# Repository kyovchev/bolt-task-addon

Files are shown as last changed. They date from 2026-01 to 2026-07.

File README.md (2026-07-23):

# Bolt Task Addon for Task Board TBv2023

This repository contains the Bolt Task Addon for Task Board version 2023 found in [https://github.com/peterso/robotlearningblock](https://github.com/peterso/robotlearningblock).

The Bolt Task requires the robot to unscrew a bolt, move it to another position and screw it again. During the operation the robot must not exceed predefined pressure force over the bolt task assembly.

**IMPORTANT NOTE: The latest version is Type B V2. It uses M8x30mm bolt and provides brackets for direct mount to the box or to a DIN rail.**

## Introduction

Two different protopyes of the task addon are developed:
- **Type A**
   
   The presence of the bolt is detected by two [M5Stack Unit 180](https://docs.m5stack.com/en/unit/OP180).
   
   Video demonstration of the first Type A prototype and the task performed by a human can be found in the following video [https://youtu.be/7AfbINjLBa4](https://youtu.be/7AfbINjLBa4):

   Bolt Task Addon Type A for TBv2023 - First Prototype Demo (https://youtu.be/7AfbINjLBa4)

- **Type B**

   The presence of the bolt is detected by simple circuit connection similar to the connection of the terminal block of TBv2023 for PbHub port 3 as decribed in the original [peterso/robotlearningblock/Assembly of Task Board 2023_V2.pdf](https://drive.google.com/file/d/1LZS_wPafdJOO1Q0lu-8TDO9xGrxpoSBB/view?usp=sharing).

   The Type B design is more compact and might be used together wih the terminal block if more digital pins are available or second hub is added. This design checks whether the bolt is fully tightened. After the bolt is slightly loose there will be no signal on the digital pins. The robot will need to do 3 full turns to release the bolt.

   Video demonstration of the first Type B prototype and the task performed by a human can be found in the following video [https://youtu.be/U2pmAaK7oM4](https://youtu.be/U2pmAaK7oM4):

   Bolt Task Addon Type B for TBv2023 - First Prototype Demo (https://youtu.be/U2pmAaK7oM4)

## Force measurement

For both designs the force is measured by one [M5Stack Unit Mini Scales (SKU:U177)](https://docs.m5stack.com/en/unit/Unit-Mini%20Scales).

Sample graphing of the force on the scales unit during operation when Type B design is used is shown in the following figure:

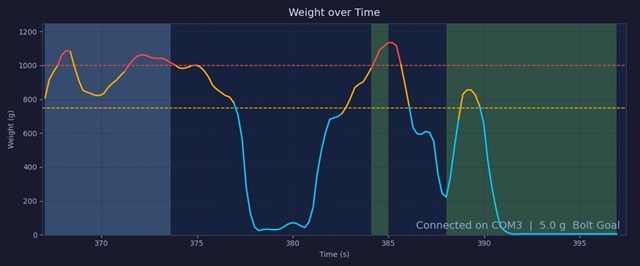
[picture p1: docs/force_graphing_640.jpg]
Force Graphing


Video demonstration of the measured force when Type B design is used is shown in the following video [https://youtu.be/ekPisNhrMn4](https://youtu.be/ekPisNhrMn4):

Bolt Task Addon Type B for TBv2023 - Force Measurement Demo (https://youtu.be/ekPisNhrMn4)

## Firmware

The used controller is [M5StickC-Plus2](https://docs.m5stack.com/en/core/M5StickC%20PLUS2). On the display visual feedback is provided. When the bolt is in the start position and at least 12 bolt revolutions are executed the top (left) part of the screen is blue. When the bolt is in the end position and at least 12 bolt revolutions are executed the bottom (right) part of the screen is green. When the pressure is near the max limit the screen will turn yellow. When the pressure is over the limit the screen will turn red. The Arduino test code of the first prototype for:
- **Type A** is in the folder [./M5StickCPlus2-Arduino/BoltTaskTestTypeA/](./M5StickCPlus2-Arduino/BoltTaskTestTypeA/).

- **Type B** is in the folder [./M5StickCPlus2-Arduino/BoltTaskTestTypeB/](./M5StickCPlus2-Arduino/BoltTaskTestTypeB/).

- **Type B with force graphing** firmware is in the folder [./M5StickCPlus2-Arduino/GraphingTestTypeB/](./M5StickCPlus2-Arduino/GraphingTestTypeB/). By pressing the M5 button you can toggle the graphing display. This firmware is also sending the data via serial communication. [./M5StickCPlus2-Arduino/GraphicsTestTypeB/live_graph.py](./M5StickCPlus2-Arduino/GraphingTestTypeB/live_graph.py) is a Python script for visualization of the data. Read the comments in the beggining of the file for information about the usage.

IDF and Arduino compatible firmwares for the fully assembled Task Board v2023 with the added Bolt Task Addon can be found in the folder [./TBv2023-Firmware/](./TBv2023-Firmware/).

## CAD

The Bolt Task Addon can be 3D Printed. The STLs of the parts are in the folder [./STLs/](./STLs/).

The repository contains the FreeCAD ([https://www.freecad.org/](https://www.freecad.org/)) design file for the diferrent designs:

- **Type A**

   The design file is [/CAD/BoltTaskAssembly_TypeA_V1.FCStd](/CAD/BoltTaskAssembly_TypeA_V1.FCStd).

   The Type A CAD assembly of the Bolt Task Addon is shown in the following image:

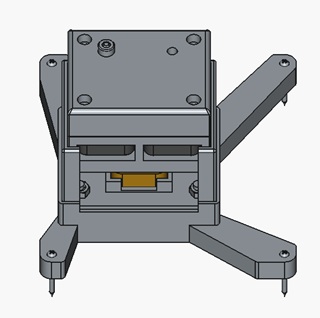
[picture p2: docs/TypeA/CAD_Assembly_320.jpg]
CAD Assembly
   

   The printed parts and the M5 Unit sensors are shown in the following image:

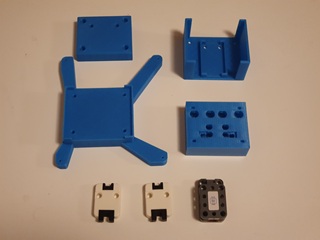
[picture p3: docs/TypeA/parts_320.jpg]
Printed Parts and M5 Unit Sensors
   

   The complete assembly mounted on the CU-3286-MB box is shown in the following image:

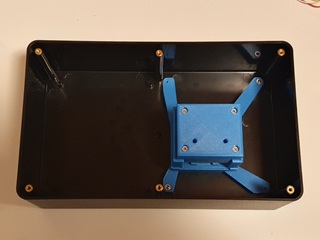
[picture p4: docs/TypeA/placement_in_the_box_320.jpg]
   

   Place two M4 nuts between the main and the top part to be used for bolt threads as shown in the image:

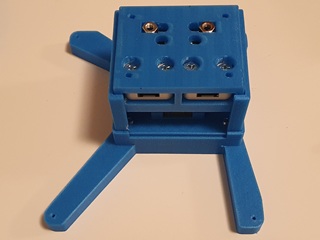
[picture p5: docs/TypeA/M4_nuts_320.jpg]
M4 nuts
   

   The Bolt Task Addon Type A with the cover of the TBv2023 is shown in the following image:
   
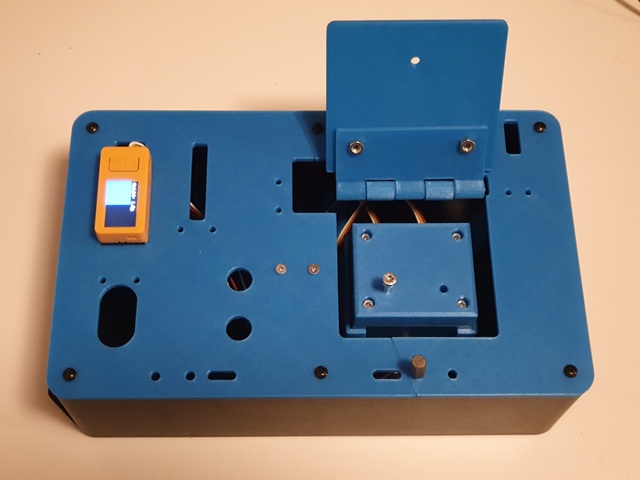
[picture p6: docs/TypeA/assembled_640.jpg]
   

- **Type B V1**

   The design file is [/CAD/BoltTaskAssembly_TypeB_V1.FCStd](/CAD/BoltTaskAssembly_TypeB_V1.FCStd).

   The Type B V1 CAD assembly of the Bolt Task Addon is shown in the following image:

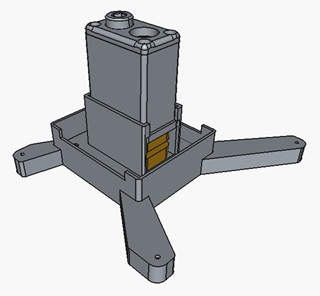
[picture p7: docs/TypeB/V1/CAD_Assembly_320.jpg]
CAD Assembly
   

   For this design we are using M8x40mm bolt. The used washers are one with InnerD=10.50mm, OuterD=19.80mm, Thickness=1.77mm and two InnerD=5.30mm, OuterD=14.85mm, Thickness=1.18mm. The printed parts, the M5 Mini Scales and the used hardware are shown in the following image:

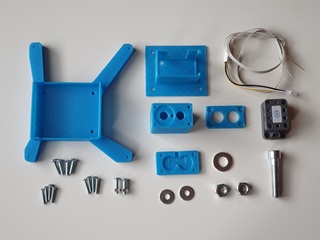
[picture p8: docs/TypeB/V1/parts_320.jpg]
Printed Parts and Hardware
   

   The washers and the M8 nuts must be placed together with the cable going to port 3 of the PbHub as shown in the following image. The black cable must be connected to the top (the bigger) washer, the white cable is to be connected to the small washer which is below the nut ot the bolt start position and the yellow cable is to be connected to the nut below the bolt goal position. The cables must be positioned carefully so that they are not pinched by the washers when the bolt is tightened. The black cable must be routed through the hole in the main block.

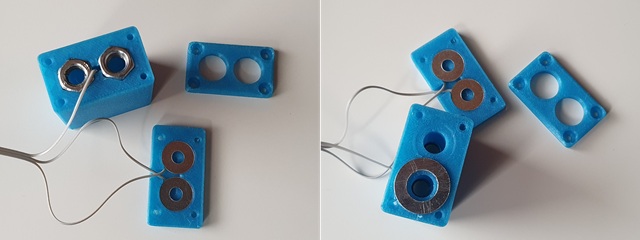
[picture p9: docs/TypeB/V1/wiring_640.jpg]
Wiring
   

   After the cables are routed then the three parts are assembled together with 8 M3 screws. Depending on the washers and the 3D print quality you might need to add one additional M3 or M4 washer between the M8 nut and the bottom washer. The M8 nut must touch the bottom washer to close the circuit with the M8 bolt. Further versions might use separate bottom caps to address this issue.

   The M5 Unit Mini Scales is attached to the base with two M4 screws. The bolt assembly is then snapped in to place on top of the base assembly. Currently, the scale is not attached with bolts to the bolt assembly. Then, the assembly is attached to the bottom bracket with 4 M4 screws and the complete assembly is mounted on the CU-3286-MB box as shown in the following image:

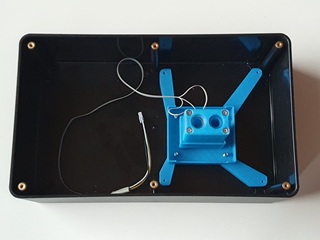
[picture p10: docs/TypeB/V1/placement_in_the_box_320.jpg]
   

   The Bolt Task Addon Type B with the cover of the TBv2023 is shown in the following image:

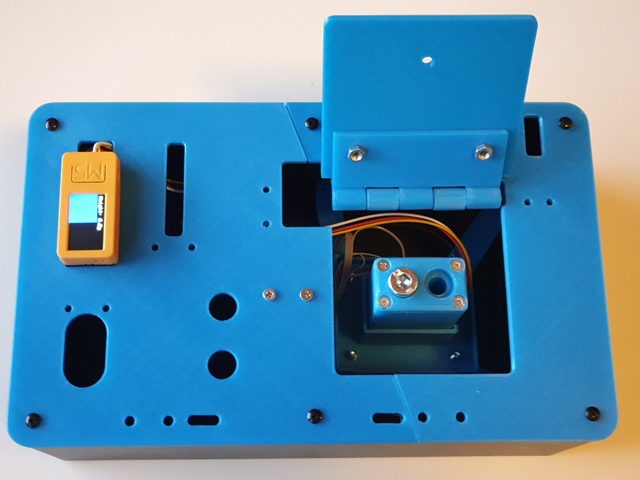
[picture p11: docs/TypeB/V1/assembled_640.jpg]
   

- **Type B V2**

   The design file is [/CAD/BoltTaskAssembly_TypeB_V2.FCStd](/CAD/BoltTaskAssembly_TypeB_V2.FCStd). There are also STEP file exports in the folder [./CAD/STEPs/](./CAD/STEPs/) which can be imported easily into other CAD softwares.

   The Type B V2 CAD assembly of the Bolt Task Addon is shown in the following image:

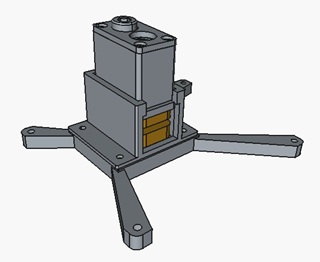
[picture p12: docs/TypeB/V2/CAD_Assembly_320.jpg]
CAD Assembly
   

   For this design we are using **M8x30mm** bolt. The used washers are one with InnerD=10.50mm, OuterD=19.80mm, Thickness=1.77mm and two InnerD=4.20mm, OuterD=11.80mm, Thickness=1.10mm.

   **Note:** You can also use a shorter **M8x25mm** bolt by using the provided [./STLs/TypeB/V2/Main_25mm.stl](./STLs/TypeB/V2/Main_25mm.stl) instead of Main.stl.

   The printed parts, the M5 Mini Scales and the used hardware are shown in the following image:

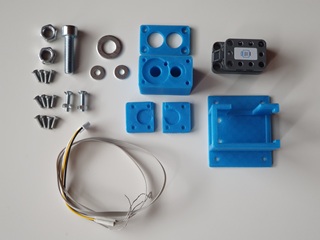
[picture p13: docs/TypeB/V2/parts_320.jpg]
Printed Parts and Hardware
   

   The washers and the M8 nuts must be placed together with the cable going to port 3 of the PbHub. The black cable must be connected to the top (the bigger) washer, the white cable is to be connected to the small washer which is below the nut ot the bolt start position and the yellow cable is to be connected to the nut below the bolt goal position. The cables must be positioned carefully so that they are not pinched by the washers when the bolt is tightened. The black cable must be routed through the hole in the main block.

   After the cables are routed then the parts are assembled together with 12 M3 screws. The M8 nuts must touch the bottom washers to close the circuit with the M8 bolt.

   The M5 Unit Mini Scales is attached to the base with two M4 screws. The bolt assembly is then snapped in to place on top of the base assembly. Currently, the scale is not attached with bolts to the bolt assembly. The assembly process is shown in the following video  [https://youtu.be/teUUwNURSHQ](https://youtu.be/teUUwNURSHQ):

   Bolt Task Addon Type B V2 for TBv2023 - Assembly Process (https://youtu.be/teUUwNURSHQ)

   After initial testing, the base part was modified to withstand a higher load. A comparison between the original and modified base is shown in the figure:

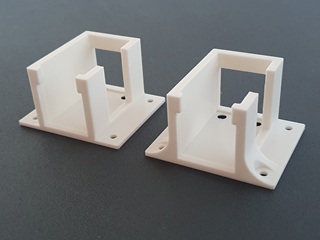
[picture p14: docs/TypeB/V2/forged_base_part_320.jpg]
Forged Base Comparison
   

   Then, the assembly is attached to the bottom bracket or DIN rail with 4 M4 screws. The complete assembly can be mounted on the CU-3286-MB box is two ways:
   - with the provided DIN rail attachments and clamping mounting blocks:

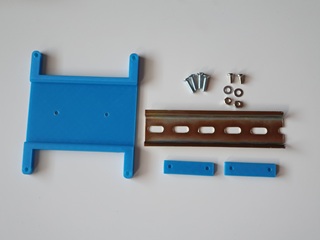
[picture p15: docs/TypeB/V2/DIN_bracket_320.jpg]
DIN bracket
      

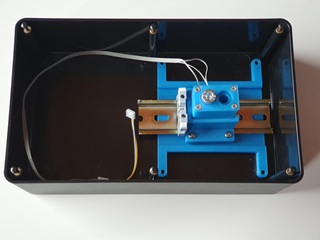
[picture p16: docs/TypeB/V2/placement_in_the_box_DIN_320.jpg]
      

   - directly to the box with the provided bracket:

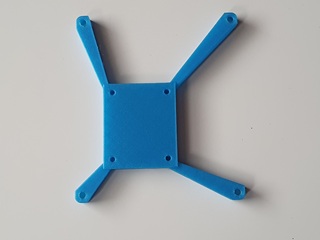
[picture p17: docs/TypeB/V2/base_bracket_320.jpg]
Base Bracket
      

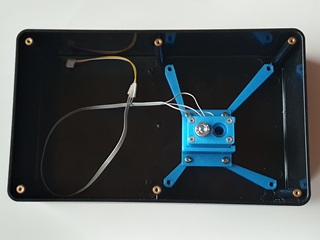
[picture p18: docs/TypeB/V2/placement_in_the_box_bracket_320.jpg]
      

   The Bolt Task Addon Type B V2 with the cover of the TBv2023 is shown in the following images:

   - with DIN rail:

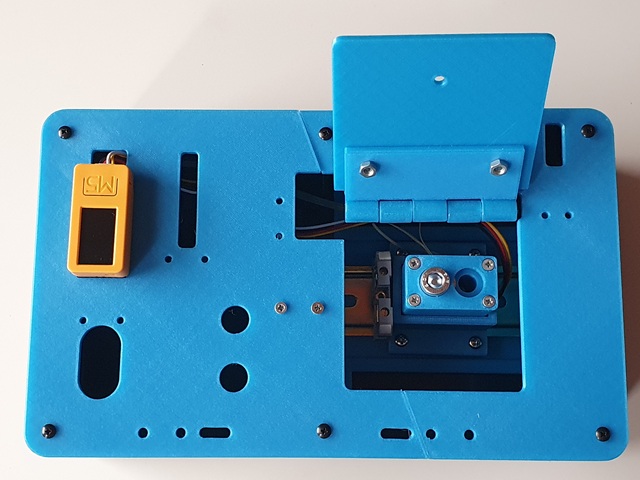
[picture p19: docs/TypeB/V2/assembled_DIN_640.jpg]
      

   - directly to the box:

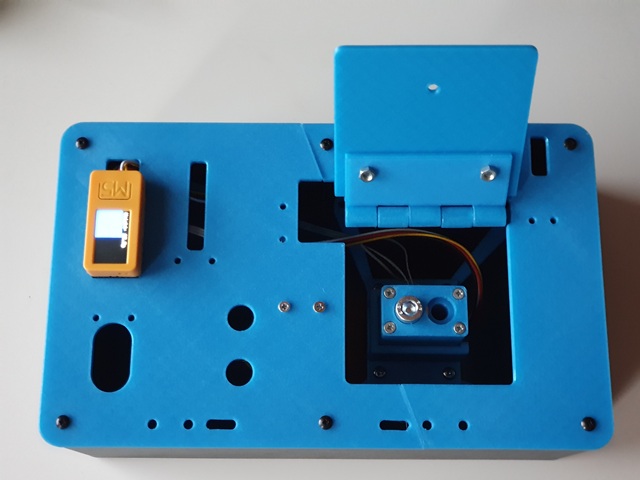
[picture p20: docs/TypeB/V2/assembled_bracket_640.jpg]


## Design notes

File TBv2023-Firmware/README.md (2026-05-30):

# Firmware for Task Board v2023 with Bolt Task Addon

This folder contains Arduino and IDF firmwares for the Task Board v2023 with the Bolt Task Addon. They are compatible with the older end-of-life M5StickC Plus2 and the current M5Stack StickS3.

The Arduino firmware is very basic and shows how to interact with all of the sensors. The Arduino firmware is in the folder [./Arduino/TBv2023_Bolt_Task_Addon/](./Arduino/TBv2023_Bolt_Task_Addon/).

The IDF firmware is an extension of the original firmware. It just made compatible with the new sensors and the newer StickS3. The original version of the firmware can be found at [https://github.com/peterso/robotlearningblock/tree/main/idf/taskboard](https://github.com/peterso/robotlearningblock/tree/main/idf/taskboard). More information about the instalation procedure can be found in the folder [./IDF/](./IDF/).

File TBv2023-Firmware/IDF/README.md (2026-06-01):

# Task Board v2023 with Bolt Task Addon IDF Firmware

The original IDF firmware can be found here: [https://github.com/peterso/robotlearningblock/tree/main/idf/taskboard](https://github.com/peterso/robotlearningblock/tree/main/idf/taskboard).

The files in the patch directory provide an easy way to extend thi original firmware and to add support for the newer M5Stack StickS3 board and for the developed Bolt Task Addon.

You can compile and flash the board with the new firmware as follows:

1. Clone this repository:
    ```bash
    git clone https://github.com/kyovchev/bolt-task-addon.git
    cd bolt-task-addon/TBv2023-Firmware/IDF
    ```

2. Clone the original IDF firmware and patch it with the updated code:
    ```bash
    git clone https://github.com/kyovchev/robotlearningblock
    cd robotlearningblock
    git submodule update --init --recursive
    cd idf/taskboard/
    rm -rf components/m5stack__m5unified/
    rm sdkconfig sdkconfig.old dependencies.lock
    sudo rm -rf build
    sudo rm -rf managed_components
    cp -rf ../../../patch/* .
    ```

3. Run the `espressif/idf:release-v5.3` docker:
    ```bash
    docker run -it --rm   -v $PWD:/workspace   -v /dev:/dev   --privileged   espressif/idf:release-v5.3
    ```

4. Inside of the docker install the required build packages:
    ```bash
    pip3 install catkin_pkg lark-parser colcon-common-extensions empy==3.3.4
    cd workspace
    ```

5. Select the target board.

    4.1. For the M5StickC-Plus2 use:
    ```bash
    idf.py set-target esp32
    ```

    4.2. For the M5 StickS3 use:
    ```bash
    idf.py set-target esp32s3
    ```

6. Select the correct task board hardware configuration in the menu:
    ```bash
    idf.py menuconfig
    ```
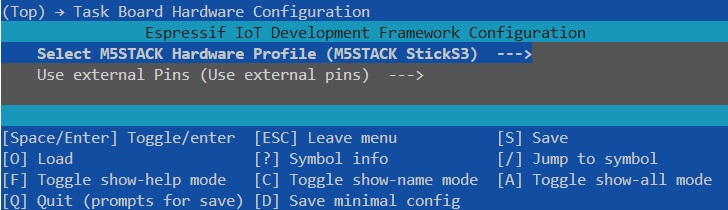
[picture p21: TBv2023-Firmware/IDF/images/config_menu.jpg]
Hardware Configuration Menu
    

7. Next you need to build the firmware:

    6.1. For the M5StickC-Plus2 use:
    ```bash
    idf.py build
    ```

    6.2. For the M5 StickS3 you might need to remove duplicated atomic_64bits before executing the build command:
    ```bash
    idf.py build
    /opt/esp/tools/xtensa-esp-elf/esp-13.2.0_20250707/xtensa-esp-elf/bin/xtensa-esp32s3-elf-ar -d /workspace/components/micro_ros_espidf_component/libmicroros.a librcutils-atomic_64bits.c.obj
    idf.py build
    ```

8. Flash the firmware:
    ```bash
    idf.py flash
    ```

9. You can use the debug monitor with:
    ```bash
    idf.py monitor
    ```

---

The order of the sensors in the PbHub and/or external pins are as follows:

- without the special Y cable:

    0 - Dual button

    1 - Left photo int sensor

    2 - Right photo int sensor

    3 - Terminal blocks

    4 - Angle sensor

    5 - Potentiometer fader

    Bottom left pins (GND, G26, G25) or (GND, G0, G1) of the corresponding M5StickC-Plus2 or StickS3 for the bolt task addon:
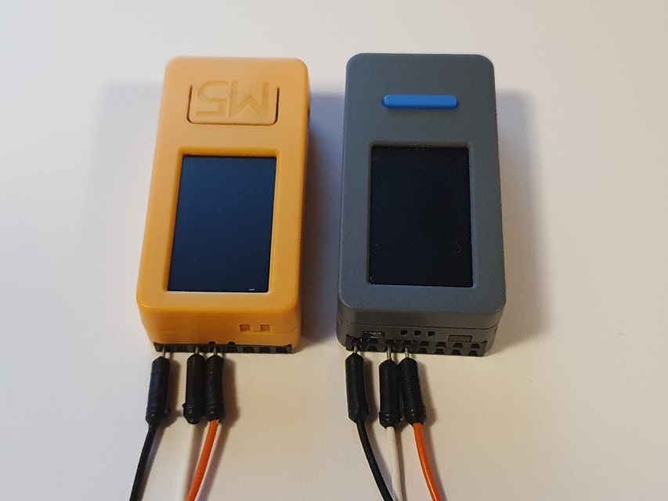
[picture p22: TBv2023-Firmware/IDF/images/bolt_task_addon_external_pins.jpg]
External Pins
        

- with the special Y cable:

    0 - Dual button

    1 - Both left and right photo int sensor connected to the custom cable:
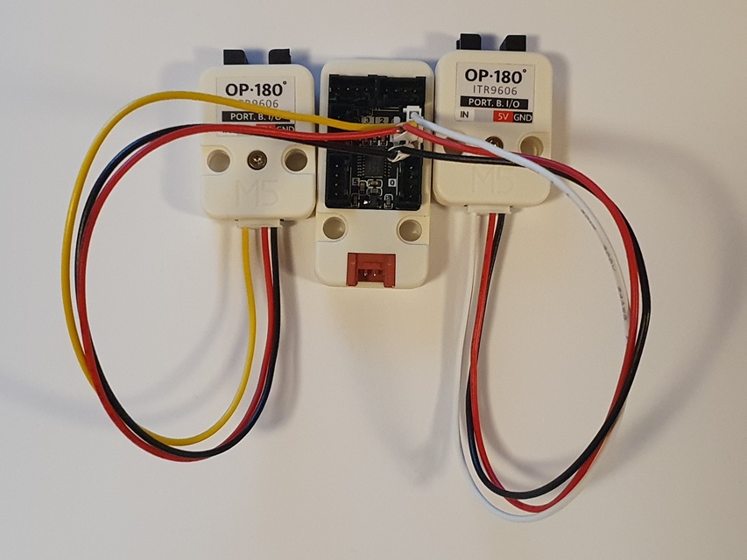
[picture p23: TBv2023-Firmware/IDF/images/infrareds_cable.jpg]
Infrareds Cable
        

    2 - Bolt task addon

    3 - Terminal blocks

    4 - Angle sensor

    5 - Potentiometer fader

---

More informartion about the usage of the firware can be found in the Robothon Task Board Firmware documentation: [https://github.com/peterso/robotlearningblock/blob/main/idf/taskboard/README.md](https://github.com/peterso/robotlearningblock/blob/main/idf/taskboard/README.md).

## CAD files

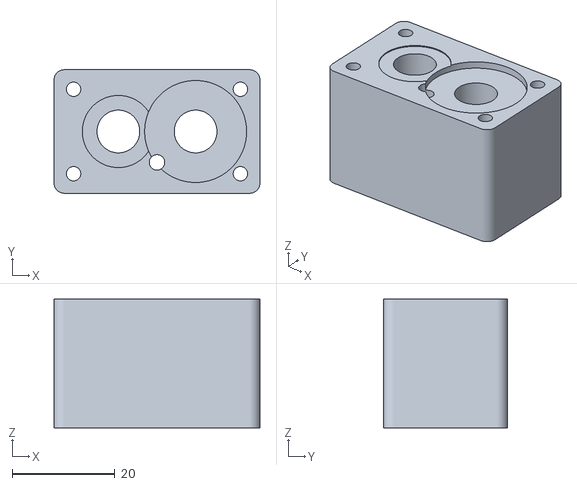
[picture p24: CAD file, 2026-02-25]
STLs/TypeB/V2/Main_25mm.stl
40.0 x 24.0 x 25.0

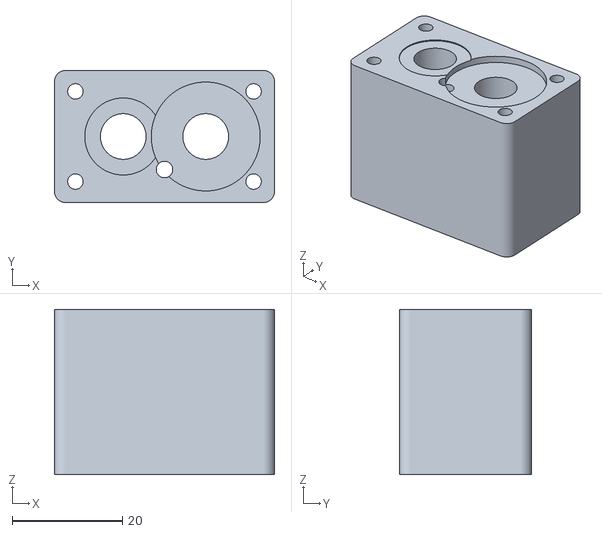
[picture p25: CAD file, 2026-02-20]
STLs/TypeB/V2/Main.stl
40.0 x 24.0 x 30.0

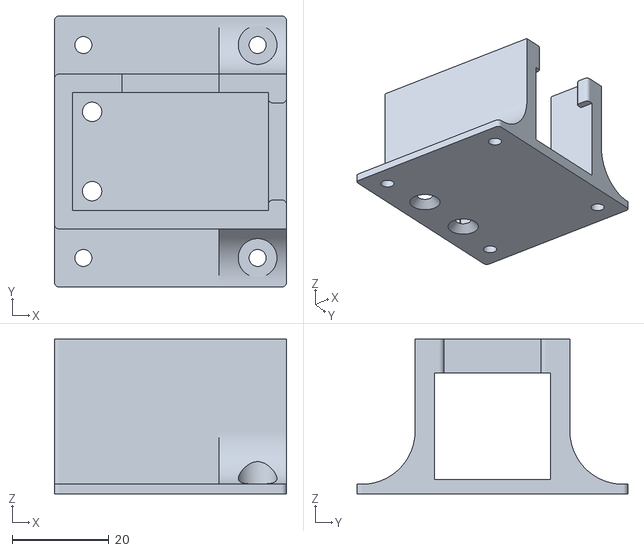
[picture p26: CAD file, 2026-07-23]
STLs/TypeB/V2/Base_Forged.stl
48.0 x 56.0 x 32.0

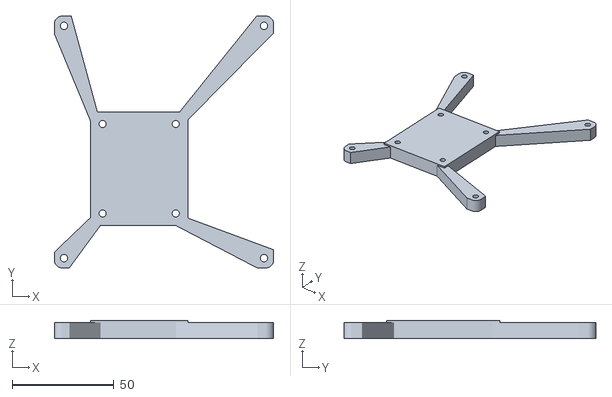
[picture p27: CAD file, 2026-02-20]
STLs/TypeB/V2/BracketBase.stl
108.0 x 124.0 x 9.00

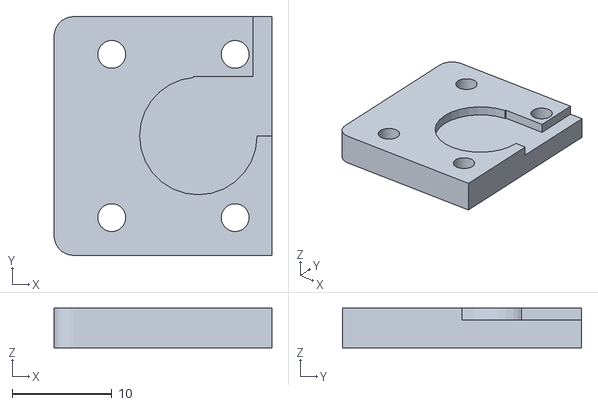
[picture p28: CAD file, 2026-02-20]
STLs/TypeB/V2/BottomRight.stl
21.9 x 24.0 x 4.00

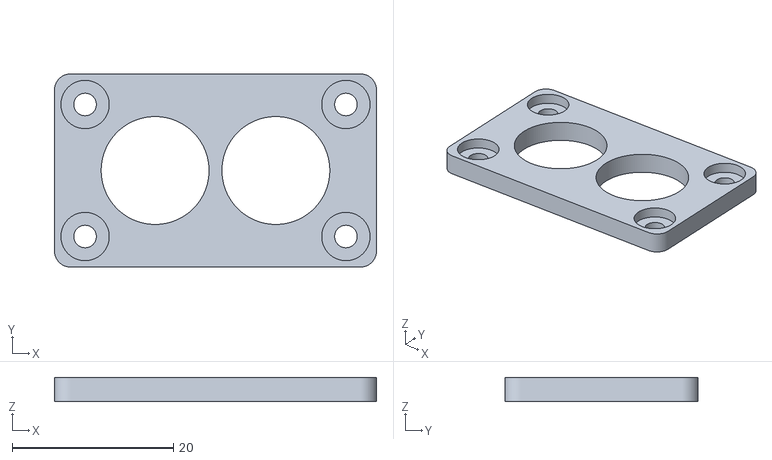
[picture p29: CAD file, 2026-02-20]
STLs/TypeB/V2/Top.stl
40.0 x 24.0 x 3.00

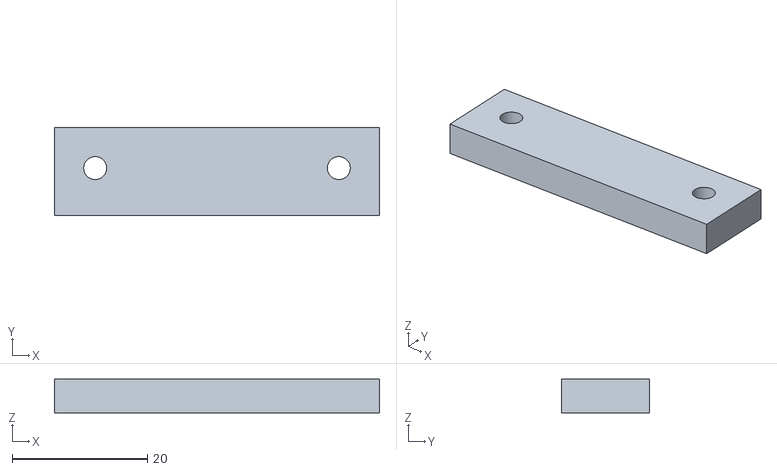
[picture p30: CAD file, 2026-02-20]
STLs/TypeB/V2/BaseMountBlockDIN.stl
48.0 x 13.0 x 5.00

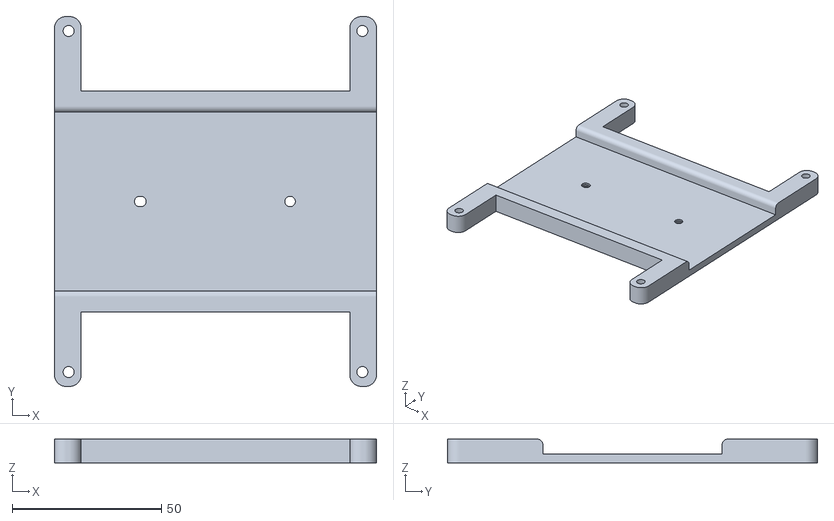
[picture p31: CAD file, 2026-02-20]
STLs/TypeB/V2/BracketDIN.stl
108.0 x 124.0 x 8.00

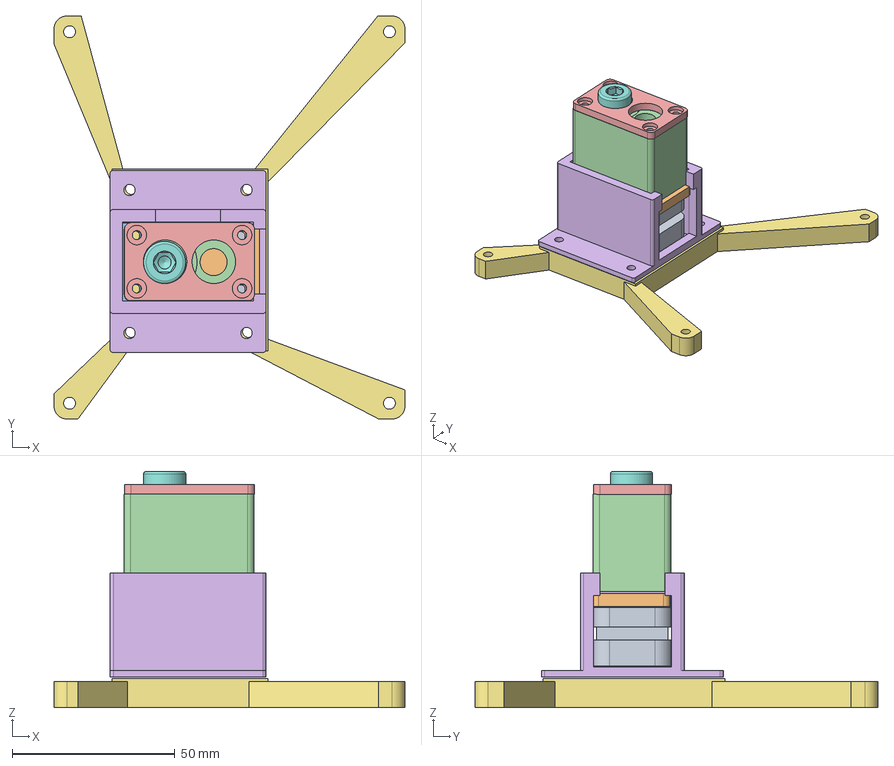
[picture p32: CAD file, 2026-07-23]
CAD/BoltTaskAssembly_TypeB_V2.FCStd
108.0 x 124.0 x 72.7 mm
UnitMiniScale
BottomLeft
BottomRight
Main
Top
Base
BracketBase
M8x30-Screw

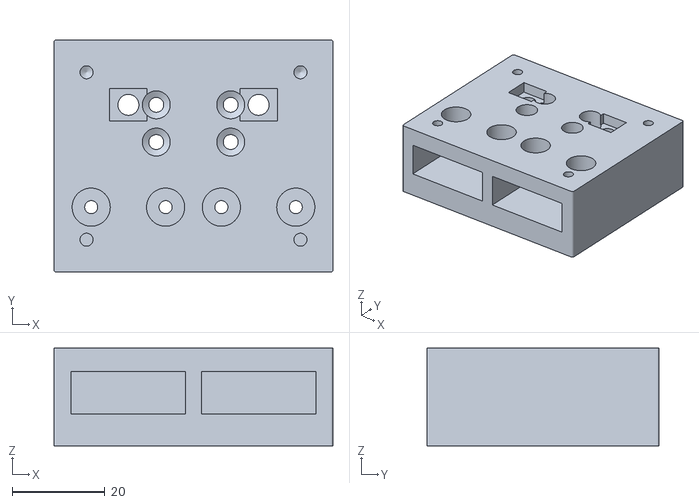
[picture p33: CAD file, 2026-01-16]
STLs/TypeA/BoltTaskAssembly_TypeA_V1-Main.stl
60.0 x 50.0 x 21.0

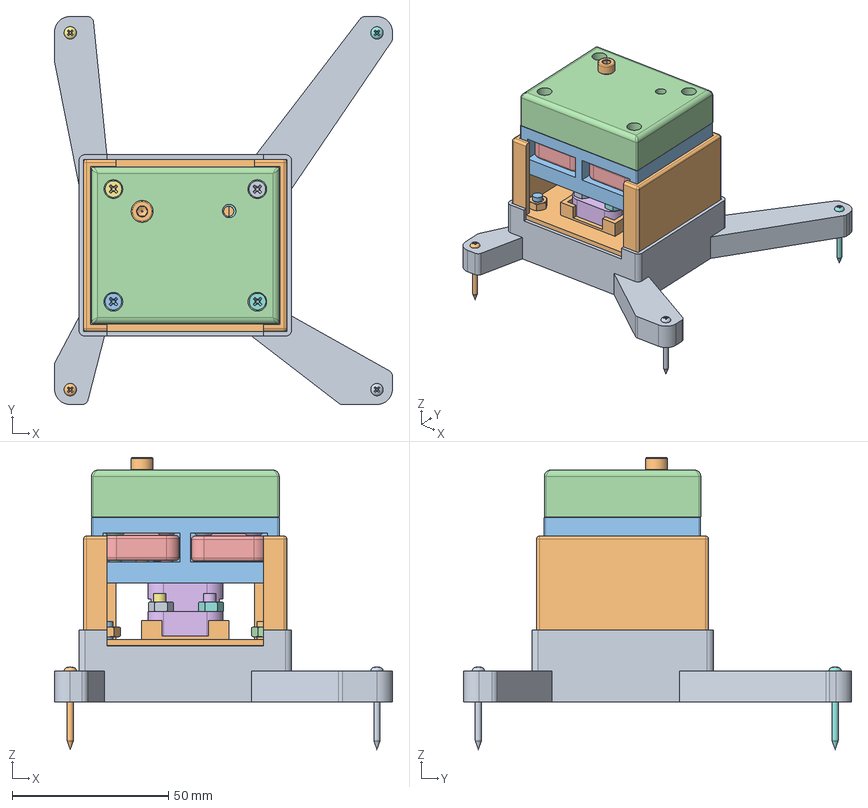
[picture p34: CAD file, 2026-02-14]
CAD/BoltTaskAssembly_TypeA_V1.FCStd
108.0 x 124.0 x 93.3 mm
BaseBracket
Base
Main
Top
UnitOP180 x 2
UnitMiniScale
M3x16-Screw
M3x16-Screw016
M3x16-Screw017
M4x35-Screw
M3x16-Screw018
M4x16-Screw
M4x16-Screw013
M4x16-Screw011
M4-Nut001
M4-Nut
M4x16-Screw014
M3x16-Screw027
M3x16-Screw028
M3x16-Screw029
M3x16-Screw030
M3-Nut003
M3-Nut006
M3-Nut007
M3-Nut
M4x25-Screw003
M4x25-Screw
M4x25-Screw001
M4x25-Screw002
M4x16-Screw023
M4x16-Screw024
M4-Nut004
M4-Nut005
M4-Nut009
M4-Nut011
M4-Nut012
M4-Nut016
M4-Nut015
2 mmx25-Screw003
2 mmx25-Screw
2 mmx25-Screw005
2 mmx25-Screw006

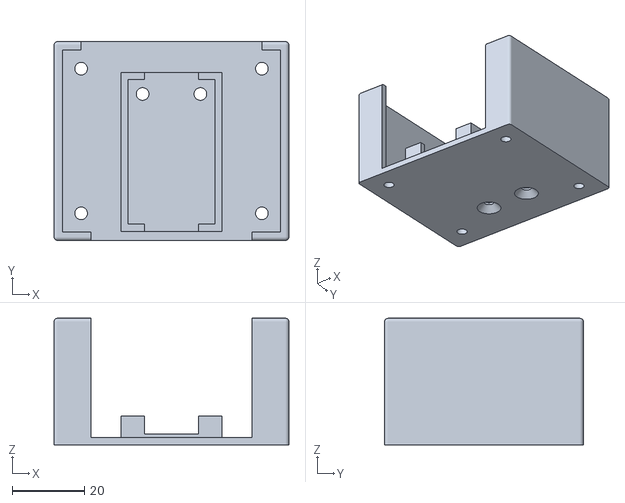
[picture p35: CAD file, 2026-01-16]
STLs/TypeA/BoltTaskAssembly_TypeA_V1-Base.stl
65.0 x 55.0 x 35.0

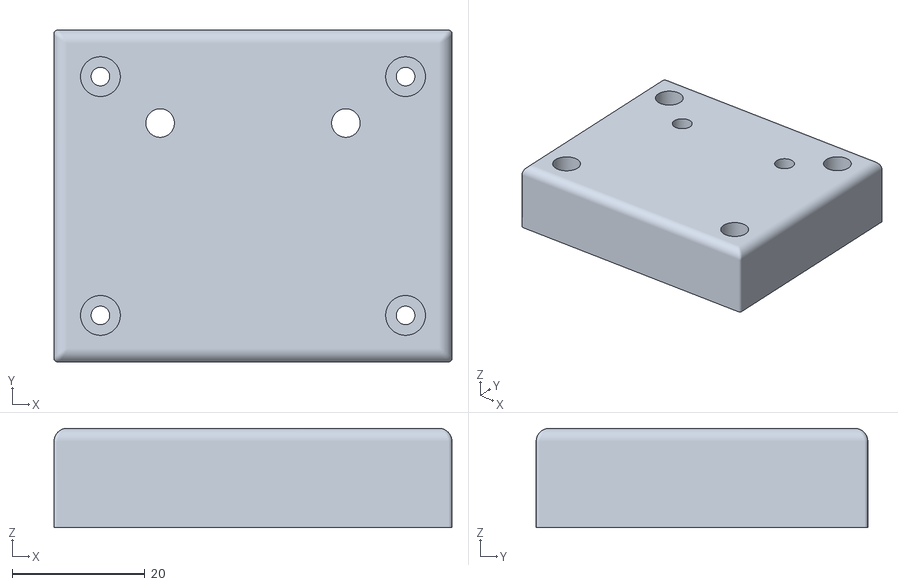
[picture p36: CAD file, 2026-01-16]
STLs/TypeA/BoltTaskAssembly_TypeA_V1-Top.stl
60.0 x 50.0 x 15.0

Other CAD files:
STLs/TypeB/V2/Base.stl
STLs/TypeB/V2/BottomLeft.stl
CAD/STEPs/BoltTaskAssembly_TypeB_V2-Assembly.step
CAD/STEPs/BoltTaskAssembly_TypeB_V2-Main_25mm.step
CAD/STEPs/BoltTaskAssembly_TypeB_V2-BracketDIN.step
CAD/BoltTaskAssembly_TypeB_V1.FCStd
CAD/STEPs/BoltTaskAssembly_TypeB_V2-Base.step
CAD/STEPs/BoltTaskAssembly_TypeB_V2-BaseMountBlockDIN.step
CAD/STEPs/BoltTaskAssembly_TypeB_V2-BottomLeft.step
CAD/STEPs/BoltTaskAssembly_TypeB_V2-BottomRight.step
CAD/STEPs/BoltTaskAssembly_TypeB_V2-BracketBase.step
CAD/STEPs/BoltTaskAssembly_TypeB_V2-Main.step
CAD/STEPs/BoltTaskAssembly_TypeB_V2-Top.step
CAD/STEPs/BoltTaskAssembly_TypeB_V2-UnitMiniScale.step
STLs/TypeA/BoltTaskAssembly_TypeA_V1-BaseBracket.stl
STLs/TypeB/V1/BoltTaskAssembly_TypeB_V1-Base.stl
STLs/TypeB/V1/BoltTaskAssembly_TypeB_V1-BaseBracket.stl
STLs/TypeB/V1/BoltTaskAssembly_TypeB_V1-Bottom.stl
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

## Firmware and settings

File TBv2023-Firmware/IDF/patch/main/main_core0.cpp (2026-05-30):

/**
 * Robothon Task Board Firmware
 */

#include <sdkconfig.h>

#include <hal/board/TaskBoardDriver_TBv2023_BoltAddon.hpp>

#include <util/Timing.hpp>
#include <network/HTTPServer.hpp>
#include <network/WifiManager.hpp>
#include <network/OTAUpdater.hpp>
#include <network/KaaHandler.hpp>
#include <hal/NonVolatileStorage.hpp>
#include <hal/ScreenController.hpp>
#include <hal/PaHubToPbHubController.hpp>
#include <hal/PbHubController.hpp>
#include <hal/HardwareLowLevelController.hpp>
#include <microros/MicroROS.hpp>
#include <microros/MicroROSController.hpp>
#include <version.hpp>

#include <esp_log.h>
#include <nvs_flash.h>
#include <esp_event.h>
#include <esp_wifi.h>

#include <freertos/FreeRTOS.h>
#include <freertos/task.h>
#include <freertos/semphr.h>

// Forward declarations
struct WebSocketTaskArgs
{
    HTTPServer& http_server;
    TaskBoardDriver& task_board_driver;
    TaskExecutor& task_executor;
    MicroROSController& micro_ros_controller;
};

void websockets_task(
        void* args);

/**
 * @brief GPIO configuration
 */
void config_gpios()
{
    esp_err_t ret_output;
    // Set GPIO 19 to output mode
    ret_output = gpio_reset_pin(GPIO_NUM_19);
    if (ret_output != ESP_OK) {
        ESP_LOGE("GPIO", "Failed to reset pin 19");
        return;
    }
    ret_output = gpio_set_direction(GPIO_NUM_19, GPIO_MODE_OUTPUT);
    if (ret_output != ESP_OK) {
        ESP_LOGE("GPIO", "Failed to set pin 19 direction");
        return;
    }
    // Cycle the solenoid at start up
    ret_output = gpio_set_level(GPIO_NUM_19, 1);
    if (ret_output != ESP_OK) {
        ESP_LOGE("GPIO", "Failed to set pin 19 level");
        return;
    }
    vTaskDelay(pdMS_TO_TICKS(1000));
    ret_output = gpio_set_level(GPIO_NUM_19, 0);
    if (ret_output != ESP_OK) {
        ESP_LOGE("GPIO", "Failed to set pin 19 level");
        return;
    }
}

/**
 * @brief Deactivate the solenoid
 */
void deactivate_solenoid()
{
    esp_err_t ret_output;
    ret_output = gpio_set_level(GPIO_NUM_19, 0);
    if (ret_output != ESP_OK) {
        ESP_LOGE("GPIO", "Failed to set pin 19 level");
        return;
    }
}

TimerHandle_t timer_solenoid_ = xTimerCreate(   //< Timer to turn solenoid off
    "SolenoidOff",         // Timer name
    pdMS_TO_TICKS(5000),   // Delay in ms
    pdFALSE,               // Disabled auto-reload
    nullptr,
    [](TimerHandle_t xTimer) {  // Callback
        // Turn solenoid off
        deactivate_solenoid();
    }
);

/**
 * @brief Activate the solenoid for 5 seconds
 */
void activate_solenoid()
{
    esp_err_t ret_output;
    ret_output = gpio_set_level(GPIO_NUM_19, 1);
    if (ret_output != ESP_OK) {
        ESP_LOGE("GPIO", "Failed to set pin 19 level");
        return;
    }
    if (timer_solenoid_ != nullptr) {
        xTimerStart(timer_solenoid_, 0);
    }
}

/**
 * @brief System entry point
 */
extern "C" void app_main(
        void)
{
    // config_gpios();

    // ------------------------
    // System Initialization
    // ------------------------

    // Initialize Non-Volatile Storage (NVS) flash memory
    // If no free pages are available or a new version is found, erase and reinitialize
    esp_err_t ret = nvs_flash_init();

    if (ret == ESP_ERR_NVS_NO_FREE_PAGES || ret == ESP_ERR_NVS_NEW_VERSION_FOUND)
    {
        ESP_ERROR_CHECK(nvs_flash_erase());
        ESP_ERROR_CHECK(nvs_flash_init());
    }

    // Initialize TCP/IP stack for network communications
    ESP_ERROR_CHECK(esp_netif_init());

    // Create default event loop for system events
    ESP_ERROR_CHECK(esp_event_loop_create_default());

    // Disable Power Save modes for improved performance
    esp_wifi_set_ps(WIFI_PS_NONE);

    // ------------------------
    // Hardware Initialization
    // ------------------------

    // Initialize M5Stack hardware
    M5.begin();

    // Initialize hardware controllers and drivers
    TaskBoardDriver_v1 task_board_driver_v1(M5);
    TaskBoardDriver& task_board_driver = task_board_driver_v1;
    ScreenController screen_controller(task_board_driver.get_hardware_low_level_controller());
    NonVolatileStorage non_volatile_storage(task_board_driver.get_unique_id());

    // ------------------------
    // System Setup
    // ------------------------

    // Initialize task executor
    TaskExecutor task_executor(screen_controller, non_volatile_storage);

    // Intialize screen
    screen_controller.clear();
    screen_controller.print("FW: " + FW_VERSION_STRING);
    vTaskDelay(pdMS_TO_TICKS(1000));
    screen_controller.clear();
    screen_controller.print("-> TaskExecutor started");

    // Initialize micro-ROS for ROS communication
    MicroROSController micro_ros_controller;

    // Setup HTTP server for remote control
    HTTPServer http_server(task_board_driver, task_executor, micro_ros_controller, non_volatile_storage);

    // ------------------------
    // Network Configuration
    // ------------------------

    // Update board status to read button states
    task_board_driver.update();

    // Get references to buttons
    const SensorReader& BUTTON_A = *task_board_driver.get_sensor_by_name("ON_BOARD_BUTTON_A");
    const SensorReader& BUTTON_B = *task_board_driver.get_sensor_by_name("ON_BOARD_BUTTON_B");
    const SensorReader& BUTTON_C = *task_board_driver.get_sensor_by_name("ON_BOARD_BUTTON_C");
    const SensorReader& BUTTON_PWR = *task_board_driver.get_sensor_by_name("ON_BOARD_BUTTON_PWR");
    const SensorReader& RED_BUTTON = nullptr != task_board_driver.get_sensor_by_name("RED_BUTTON") ? 
        *task_board_driver.get_sensor_by_name("RED_BUTTON") :
        *task_board_driver.get_sensor_by_name("RED_BUTTON_RIGHT");
    const SensorReader& BLUE_BUTTON = nullptr != task_board_driver.get_sensor_by_name("BLUE_BUTTON") ?
        *task_board_driver.get_sensor_by_name("BLUE_BUTTON") :
        *task_board_driver.get_sensor_by_name("BLUE_BUTTON_LEFT");

    // Check if system should start in local mode (Button A pressed during boot)
    const bool start_local_mode = BUTTON_A.read() == true;
    std::string ip_string = "";

    if (start_local_mode)
    {
        ESP_LOGI("app_main", "Starting in local mode");
        screen_controller.print("-> Starting in local mode");
        ip_string = "Local mode";
    }
    // Otherwise, initialize WiFi provisioning
    else
    {
        ESP_LOGI("app_main", "Initializing provisioning");

        // Check if WiFi credentials should be reset (Red + Blue buttons pressed)
        bool reset_provisioning = RED_BUTTON.read() == true && BLUE_BUTTON.read() == true;

        if (reset_provisioning)
        {
            screen_controller.print("-> Resetting WiFi credentials");
        }

        // Initialize WiFi manager
        WifiManager wifi_manager(http_server, task_board_driver.get_unique_ssid(), reset_provisioning);

        // Display appropriate connection instructions based on provisioning state
        if (wifi_manager.is_provisioned())
        {
            screen_controller.print("-> Trying " + wifi_manager.get_ssid());
            screen_controller.print("-> Reset with red and blue buttons");
        }
        else
        {
            screen_controller.print("-> Connect to \"" + wifi_manager.get_provisioning_ssid() + "\"");
            screen_controller.print("-> Navigate to 192.168.4.1");
        }

        // Wait for WiFi connection
        wifi_manager.wait_for_connection();

        // Display connection info
        screen_controller.print("-> Connected to " + wifi_manager.get_ssid());
        screen_controller.print("-> IP: " + wifi_manager.get_ip());
        ip_string = wifi_manager.get_ip();
    }

    // ------------------------
    // Handle OTA Updates
    // ------------------------
    if (!start_local_mode)
    {
        OTAUpdater ota_updater(screen_controller);

        // If can update, wait up to 3 seconds to red button press
        if (ota_updater.can_update())
        {
            screen_controller.clear();

            screen_controller.print("-> Red button to update to " + ota_updater.get_latest_version());

            // Wait for red button press
            for (uint32_t i = 0; i < 300; i++)
            {
                task_board_driver.update();

                if (RED_BUTTON.read() == true)
                {
                    break;
                }

                vTaskDelay(pdMS_TO_TICKS(10));
            }

            // If red button pressed, start update
            if (RED_BUTTON.read() == true)
            {
                screen_controller.print("-> Updating firmware");
                ota_updater.update();
            }

            // Skipping update
            else
            {
                screen_controller.clear();
                screen_controller.print("-> IP: " + ip_string);
            }
        }
        else
        {
            screen_controller.print("-> No updates available");
        }
    }

    // ------------------------
    // Post Network Configuration
    // ------------------------

    // Initialize HTTP API endpoints
    http_server.initialize_taskboard_api();

    // Create Micro-ROS task on core 1
    MicroROSMainArgs micro_ros_args =
    {micro_ros_controller, task_board_driver, task_executor, xTaskGetCurrentTaskHandle()};

    TaskHandle_t microros_task_handle;
    constexpr uint8_t MICROROS_THREAD_CORE_AFFINITY = 1;
    constexpr uint32_t MICROROS_STACK_SIZE = 7168;
    constexpr uint8_t MICROROS_THREAD_PRIORITY = 4;
    xTaskCreatePinnedToCore(
        microros_main,
        "microros",
        MICROROS_STACK_SIZE,
        &micro_ros_args,
        MICROROS_THREAD_PRIORITY,
        &microros_task_handle,
        MICROROS_THREAD_CORE_AFFINITY);

    // Wait for tasks
    screen_controller.print("-> Waiting tasks to start");
    screen_controller.print("-> Press Button B for default task");

    // ------------------------
    // Kaa IoT initialization
    // ------------------------
    KaaHandler kaa_handler(task_board_driver);

    TaskHandle_t kaa_task_handle;
    constexpr uint8_t KAA_THREAD_CORE_AFFINITY = 0;
    constexpr uint32_t KAA_STACK_SIZE = 5120;
    constexpr uint8_t KAA_THREAD_PRIORITY = 1;

    auto kaa_main = [](void* arg) -> void
            {
                KaaHandler* kaa_handler = static_cast<KaaHandler*>(arg);

                while (true)
                {
                    kaa_handler->send_telemetry();
                    vTaskDelay(pdMS_TO_TICKS(250));
                }
            };

    xTaskCreatePinnedToCore(
        kaa_main,
        "kaa",
        KAA_STACK_SIZE,
        &kaa_handler,
        KAA_THREAD_PRIORITY,
        &kaa_task_handle,
        KAA_THREAD_CORE_AFFINITY);

    // ------------------------
    // Websocket server
    // ------------------------
    TaskHandle_t ws_task_handle;
    constexpr uint8_t WS_THREAD_CORE_AFFINITY = 0;
    constexpr uint32_t WS_STACK_SIZE = 4096;
    constexpr uint8_t WS_THREAD_PRIORITY = 0;

    WebSocketTaskArgs ws_args = {http_server, task_board_driver, task_executor, micro_ros_controller};

    xTaskCreatePinnedToCore(
        websockets_task,
        "ws",
        WS_STACK_SIZE,
        &ws_args,
        WS_THREAD_PRIORITY,
        &ws_task_handle,
        WS_THREAD_CORE_AFFINITY);

    // ------------------------
    // Main Control Loop
    // ------------------------
    while (true)
    {
        // Update board sensor readings
        task_board_driver.update();

        // Check timeout status of current task, block forever
        bool current_task_timeout = false;
        task_executor.execute_operation_on_task(portMAX_DELAY, [&](Task* task, Task* precondition)
                {
                    const bool active_current_task = task != nullptr;
                    const bool active_current_precondition = precondition != nullptr;

                    current_task_timeout = active_current_task && !active_current_precondition &&
                    task->timeout();
                });

        // Handle Button B press - Start/Restart default task
        if (BUTTON_B.read() == true)
        {
            ESP_LOGI("app_main", "Button B pressed, launching default task");
            task_executor.cancel_task();

            // Get and configure default task
            Task& main_task = task_board_driver.get_default_task();
            Task& precondition_main_task = task_board_driver.get_default_task_precondition();

            // Set this task as a human task if the power button is pressed
            main_task.set_human_task(BUTTON_PWR.read() == true);

            // Start task execution
            task_executor.run_task(main_task, precondition_main_task);

            // Button debounce delay
            while (BUTTON_B.read() == true)
            {
                vTaskDelay(pdMS_TO_TICKS(10));
                task_board_driver.update();
            }
        }
        // Handle Button A press - Cancel current task
        else if (BUTTON_A.read() == true || current_task_timeout)
        {
            ESP_LOGI("app_main", "Button A pressed, cancelling current task");
            task_executor.cancel_task();

            // Update screen with cancellation message
            screen_controller.clear();
            screen_controller.print(current_task_timeout ? "-> Task timeout" : "-> Task cancelled");

            if (!start_local_mode)
            {
                screen_controller.print("-> IP: " + ip_string);
            }

            screen_controller.print("-> Press button B for default task");

            // Notify Micro-ROS task if it's waiting for a goal
            if (microros_task_handle != nullptr)
            {
                xTaskNotify(microros_task_handle, MANUALLY_CANCELLED_TASK, eSetBits);
            }

            // Button debounce delay
            while (BUTTON_A.read() == true)
            {
                vTaskDelay(pdMS_TO_TICKS(10));
                task_board_driver.update();
            }
        }
        // Handle Button C press - Toggle solenoid
        else if (BUTTON_C.read() == true)
        {
            ESP_LOGI("app_main", "Button C pressed, toggle solenoid");
            // briefly turn on then off the solenoid
            gpio_set_level(GPIO_NUM_19, 1);
            vTaskDelay(pdMS_TO_TICKS(500));
            gpio_set_level(GPIO_NUM_19, 0);
            
            // Button debounce delay
            while (BUTTON_C.read() == true)
            {
                vTaskDelay(pdMS_TO_TICKS(10));
                task_board_driver.update();
            }
        }

        // If notifed by Micro-ROS task, cancel current task
        uint32_t value;

        if (pdPASS == xTaskNotifyWait(pdFALSE, 0xFFFFFFFF, &value, pdMS_TO_TICKS(0)))
        {
            // Update screen with cancellation message
            screen_controller.clear();
            screen_controller.print(value == MICROROS_TIMEOUT_TASK ? "-> Task timeout" : "-> Task cancelled");
        }

        // Update task execution status
        task_executor.update();

        // Main loop delay
        vTaskDelay(pdMS_TO_TICKS(10));
    }
}

void websockets_task(
        void* arg)
{
    WebSocketTaskArgs* ws_args = static_cast<WebSocketTaskArgs*>(arg);
    HTTPServer& http_server = ws_args->http_server;
    TaskBoardDriver& task_board_driver = ws_args->task_board_driver;
    TaskExecutor& task_executor = ws_args->task_executor;
    MicroROSController& micro_ros_controller = ws_args->micro_ros_controller;

    const std::string& unique_id = task_board_driver.get_unique_id();

    auto send_task_board_status = [&http_server, &task_board_driver, &unique_id]()
            {
                JSONHandler json_handler(unique_id);
                json_handler.add_taskboard_status(task_board_driver);
                json_handler.add_custom("ws_data_type", "taskboard_status");

                char* status = json_handler.get_json_string();

                if (status != nullptr)
                {
                    http_server.send_data_to_clients((uint8_t*)status, strlen(status));
                }
            };

    auto send_system_status = [&http_server, &micro_ros_controller, &unique_id]()
            {
                JSONHandler json_handler(unique_id);
                json_handler.add_microros_info(micro_ros_controller);
                json_handler.add_freertos_summary();
                json_handler.add_custom("ws_data_type", "system_status");

                char* status = json_handler.get_json_string();

                if (status != nullptr)
                {
                    http_server.send_data_to_clients((uint8_t*)status, strlen(status));
                }
            };

    auto send_task_status = [&http_server, &task_executor, &unique_id]()
            {
                JSONHandler json_handler(unique_id);
                task_executor.execute_operation_on_task(portMAX_DELAY,
                        [&json_handler](Task* task, Task* precondition)
                        {
                            if (task != nullptr)
                            {
                                json_handler.add_task_status(*task, precondition);
                            }
                        });

                json_handler.add_custom("ws_data_type", "task_status");

                char* status = json_handler.get_json_string();

                if (status != nullptr)
                {
                    http_server.send_data_to_clients((uint8_t*)status, strlen(status));
                }
            };

    constexpr uint32_t LOOP_RATE_MS = 20;
    constexpr uint32_t TASK_BOARD_STATUS_RATE_MS = 20;
    constexpr uint32_t SYSTEM_STATUS_RATE_MS = 240;
    constexpr uint32_t TASK_STATUS_RATE_MS = 240;

    static_assert(TASK_BOARD_STATUS_RATE_MS % LOOP_RATE_MS == 0,
            "TASK_BOARD_STATUS_RATE_MS must be a multiple of LOOP_RATE_MS");
    static_assert(SYSTEM_STATUS_RATE_MS % LOOP_RATE_MS == 0,
            "SYSTEM_STATUS_RATE_MS must be a multiple of LOOP_RATE_MS");
    static_assert(TASK_STATUS_RATE_MS % LOOP_RATE_MS == 0, "TASK_STATUS_RATE_MS must be a multiple of LOOP_RATE_MS");

    uint32_t counter = 0;

    while (true)
    {
        // Send system status every TASK_BOARD_STATUS_RATE_MS
        if (counter % TASK_BOARD_STATUS_RATE_MS == 0)
        {
            send_task_board_status();
        }

        // Send system status every SYSTEM_STATUS_RATE_MS
        if (counter % SYSTEM_STATUS_RATE_MS == 0)
        {
            send_system_status();
        }

        // Send task status every TASK_STATUS_RATE_MS
        if (counter % TASK_STATUS_RATE_MS == 0)
        {
            send_task_status();
        }

        // Wait for the next loop iteration
        vTaskDelay(pdMS_TO_TICKS(LOOP_RATE_MS));
        counter += LOOP_RATE_MS;
    }
}

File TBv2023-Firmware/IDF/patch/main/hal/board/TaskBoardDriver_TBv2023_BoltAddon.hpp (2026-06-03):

/**
 * Robothon Task Board v2023 with Bolt Task Addon
 */

#pragma once

#include <hal/TaskBoardDriver.hpp>
#include <hal/HardwareLowLevelController.hpp>
#include <sensor/Sensor.hpp>
#include <sensor/AnalogFilteredSensor.hpp>
#include <sensor/CounterSensor.hpp>
#include <sensor/TriggeredSensor.hpp>
#include <task/TaskStepEqual.hpp>
#include <task/TaskStepEqualToRandom.hpp>
#include <task/TaskStepEqualDuringRandom.hpp>
#include <task/SimultaneousConditionTask.hpp>
#include <task/SequentialTask.hpp>
#include <util/Timing.hpp>

#include <esp_mac.h>

struct TaskBoardDriver_v1 : public TaskBoardDriver
{
    const char* TAG = "TaskBoardDriver_v1";

    TaskBoardDriver_v1(m5::M5Unified& m5_unified)
        : pb_hub_controller_(new PbHubController()),
          hardware_low_level_controller_(*pb_hub_controller_, m5_unified),
          scales_present_(false),
          latest_weight_(0.0f),
          scale_poll_counter_(0)
    {
        // Unique ID Generation
        uint8_t mac[6];
        esp_read_mac(mac, ESP_MAC_WIFI_STA);
        char mac_str[18];
        sprintf(mac_str, "%02X%02X%02X%02X%02X%02X", mac[0], mac[1], mac[2], mac[3], mac[4], mac[5]);
        unique_id_ = mac_str;
        char ssid_with_mac[36];
        snprintf(ssid_with_mac, sizeof(ssid_with_mac), "Task Board v2023 Bolt Addon %01X%02X", (mac[4] & 0x0F), mac[5]);
        unique_ssid_ = ssid_with_mac;

        // 1. Force explicit I2C Bus recovery configuration
        ESP_LOGI(TAG, "Initializing External I2C Bus at 100kHz for stability...");
        
        // Skip calling m5_unified.Ex_I2C.begin() to avoid driver allocation collisions!
        
        i2c_master_bus_handle_t idf_bus_handle;
        i2c_master_bus_config_t bus_cfg = {}; // Clear memory profile
        bus_cfg.i2c_port = I2C_NUM_0;          // External Peripherals Port
        #if CONFIG_M5STACK_STICK_S3
        bus_cfg.sda_io_num = GPIO_NUM_9;
        bus_cfg.scl_io_num = GPIO_NUM_10;
        #else
        bus_cfg.sda_io_num = GPIO_NUM_32;
        bus_cfg.scl_io_num = GPIO_NUM_33;
        #endif

        bus_cfg.clk_source = I2C_CLK_SRC_DEFAULT;
        bus_cfg.glitch_ignore_cnt = 7;
        bus_cfg.flags.enable_internal_pullup = 1; // Safeguard if external pull-ups are missing

        // Allocate the standard driver context
        esp_err_t bus_err = i2c_new_master_bus(&bus_cfg, &idf_bus_handle);
        if (bus_err != ESP_OK) {
            ESP_LOGE(TAG, "Failed to initialize standard I2C master bus! Error: %s", esp_err_to_name(bus_err));
        }

        // Initialize our custom controller using our safe IDF Master Bus context
        if (!pb_hub_controller_->begin(idf_bus_handle)) {
            ESP_LOGE(TAG, "CRITICAL ERROR: Failed to register I2C devices to Master Bus!");
        }
        
        // The check_status probing validation loop can now safely execute 
        while (!hardware_low_level_controller_.pb_hub_controller.check_status())
        {
            ESP_LOGI(TAG, "Waiting for PbHubController to start");
            vTaskDelay(pdMS_TO_TICKS(50));
        }

        // 2. Hardened Scales Initialization Probe Loop using the integrated controller
        ESP_LOGI(TAG, "Probing M5 Scales hardware module via Hub Controller...");
        
        // Probe check using an initial weight test read attempt
        for (int retry = 0; retry < 5; ++retry) {
            latest_weight_ = hardware_low_level_controller_.pb_hub_controller.read_scale_weight_g();
            if (latest_weight_ != -999.0f) { // If it returns anything other than a failed bus flag
                scales_present_ = true;
                break;
            }
            ESP_LOGW(TAG, "Scale not responding on bus. Retry %d/5...", retry + 1);
            vTaskDelay(pdMS_TO_TICKS(200));
        }

        if (scales_present_) {
            ESP_LOGI(TAG, "Scales hardware confirmed present. Calibrating raw offsets...");
            
            hardware_low_level_controller_.pb_hub_controller.tare_scale(); 
            vTaskDelay(pdMS_TO_TICKS(300)); // Wait period for ADC conversion loop
            hardware_low_level_controller_.pb_hub_controller.set_scale_led_color(0x001000); // Brighter Green feedback on boot success
            
            latest_weight_ = hardware_low_level_controller_.pb_hub_controller.read_scale_weight_g();
            ESP_LOGI(TAG, "Initial test weight reading: %.2f g", latest_weight_);
        } else {
            ESP_LOGW(TAG, "M5 Scales hardware module not responsive. Defaulting to fallback state.");
            latest_weight_ = 0.0f;
        }

        vTaskDelay(pdMS_TO_TICKS(100));

        // Define Sensors 
        Sensor* scale = new Sensor("SCALE", [&]()
                        {
                            return SensorMeasurement(latest_weight_);
                        });
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

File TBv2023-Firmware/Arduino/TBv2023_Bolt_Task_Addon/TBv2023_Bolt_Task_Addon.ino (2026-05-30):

#include <M5Unified.h>
#include <Wire.h>
#include "PbHubController.h"

PbHubController pb_hub;

void setup()
{
    M5.begin();
    delay(500);

    M5.Power.setExtOutput(true);
    delay(200);

    pb_hub.begin();
    delay(100);

    M5.Lcd.setTextSize(2);
    M5.Lcd.setTextColor(WHITE, BLACK);

    // I2C scan
    M5.Lcd.println("Scanning...");
    int found = 0;
    for (uint8_t addr = 1; addr < 127; addr++)
    {
        Wire.beginTransmission(addr);
        if (Wire.endTransmission() == 0)
        {
            M5.Lcd.printf("0x%02X ", addr);
            found++;
        }
    }
    if (found == 0) M5.Lcd.println("Nothing found!");
    delay(2000);
    M5.Lcd.fillScreen(BLACK);

    if (!pb_hub.check_status())
    {
        M5.Lcd.println("PbHub not found!");
        while (1) delay(500);
    }

    M5.Lcd.println("PbHub OK!");
    delay(500);
    M5.Lcd.fillScreen(BLACK);
}

void loop()
{
    M5.update();

    float weight = pb_hub.read_scale_weight_g();
    if (M5.BtnA.wasPressed()) pb_hub.tare_scale();

    bool blue_button = !pb_hub.read_digital_IO0(PbHubController::Channel::CHANNEL_0);
    bool red_button  = !pb_hub.read_digital_IO1(PbHubController::Channel::CHANNEL_0);

    bool light_left  =  pb_hub.read_digital_IO0(PbHubController::Channel::CHANNEL_1);
    bool light_right =  pb_hub.read_digital_IO0(PbHubController::Channel::CHANNEL_2);

    pb_hub.write_digital_IO0(PbHubController::Channel::CHANNEL_3, true);
    pb_hub.write_digital_IO1(PbHubController::Channel::CHANNEL_3, true);
    delay(2);
    bool probe_goal    = !pb_hub.read_digital_IO0(PbHubController::Channel::CHANNEL_3);
    bool probe_plugged = !pb_hub.read_digital_IO1(PbHubController::Channel::CHANNEL_3);

    float door_angle = pb_hub.read_analog_IO0(PbHubController::Channel::CHANNEL_4) / 4095.0f;
    float fader      = pb_hub.read_analog_IO0(PbHubController::Channel::CHANNEL_5) / 4095.0f;

    bool bolt_start = pb_hub.is_bolt_at_start();
    bool bolt_end   = pb_hub.is_bolt_at_end();

    // ── Display — fixed row positions, no \n ──────────────────────────────────
    const int COL = 0;
    const int ROW_H = 10;  // pixels per row at textSize(1)
    int row = 0;

    M5.Lcd.setTextSize(1);

    // Helper lambda: draw one fixed-width row
    auto drawRow = [&](int r, uint16_t color, const char* fmt, ...)
    {
        char buf[32];
        va_list args;
        va_start(args, fmt);
        vsnprintf(buf, sizeof(buf), fmt, args);
        va_end(args);

        // Pad to 26 chars to overwrite any leftover characters
        char padded[32];
        snprintf(padded, sizeof(padded), "%-26s", buf);

        M5.Lcd.setCursor(COL, r * ROW_H);
        M5.Lcd.setTextColor(color, BLACK);
        M5.Lcd.print(padded);
    };

    drawRow(row++, WHITE,                          "Weight:    %7.2fg", weight);
    drawRow(row++, blue_button   ? GREEN : RED,    "BLUE:      %s", blue_button   ? "PRESSED" : "released");
    drawRow(row++, red_button    ? GREEN : RED,    "RED:       %s", red_button    ? "PRESSED" : "released");
    drawRow(row++, light_left    ? GREEN : RED,    "L_LEFT:    %s", light_left    ? "ON     " : "off    ");
    drawRow(row++, light_right   ? GREEN : RED,    "L_RIGHT:   %s", light_right   ? "ON     " : "off    ");
    drawRow(row++, probe_plugged ? GREEN : RED,    "PROBE:     %s", probe_plugged ? "IN     " : "out    ");
    drawRow(row++, probe_goal    ? GREEN : RED,    "P_GOAL:    %s", probe_goal    ? "YES    " : "no     ");
    drawRow(row++, WHITE,                          "DOOR:      %5.3f", door_angle);
    drawRow(row++, WHITE,                          "FADER:     %5.3f", fader);
    drawRow(row++, bolt_start    ? GREEN : RED,    "BOLT_START:%s", bolt_start    ? "YES    " : "no     ");
    drawRow(row++, bolt_end      ? GREEN : RED,    "BOLT_END:  %s", bolt_end      ? "YES    " : "no     ");

    delay(50);
}

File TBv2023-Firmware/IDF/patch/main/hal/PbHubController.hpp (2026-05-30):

#pragma once

#include <cstring>
#include <driver/gpio.h>
#include <driver/i2c_master.h>
#include <freertos/FreeRTOS.h>
#include <freertos/task.h>

struct PbHubController
{
    static constexpr uint8_t  DEFAULT_I2C_ADDR = 0x61;
    static constexpr uint8_t  SCALE_I2C_ADDR   = 0x26;
    static constexpr uint32_t I2C_TIMEOUT_MS   = 100;

    #if CONFIG_M5STACK_STICK_S3
    static constexpr gpio_num_t PIN_BOLT_START = GPIO_NUM_0;
    static constexpr gpio_num_t PIN_BOLT_END   = GPIO_NUM_1;
    #else
    static constexpr gpio_num_t PIN_BOLT_START = GPIO_NUM_26;
    static constexpr gpio_num_t PIN_BOLT_END   = GPIO_NUM_25;
    #endif

    enum class Operation : uint8_t
    {
        WRITE_IO0       = 0x00,
        WRITE_IO1       = 0x01,
        PWM_IO0         = 0x02,
        PWM_IO1         = 0x03,
        READ_IO0        = 0x04,
        READ_IO1        = 0x05,
        ANALOG_READ_IO0 = 0x06,
    };

    enum class Channel : uint8_t
    {
        CHANNEL_0 = 0x40,
        CHANNEL_1 = 0x50,
        CHANNEL_2 = 0x60,
        CHANNEL_3 = 0x70,
        CHANNEL_4 = 0x80,
        CHANNEL_5 = 0xA0,
    };

    PbHubController() noexcept : i2c_addr_(DEFAULT_I2C_ADDR) {}

    ~PbHubController() 
    {
        if (dev_hub_handle_)   { i2c_master_bus_rm_device(dev_hub_handle_); }
        if (dev_scale_handle_) { i2c_master_bus_rm_device(dev_scale_handle_); }
    }

    /**
     * @brief Initialize GPIO inputs and register I2C slave devices to your Master Bus
     */
   bool begin(i2c_master_bus_handle_t bus_handle)
    {
        init_gpio_inputs();
        bus_handle_ = bus_handle; // Store the bus handle for probing later

        // 1. Configure and add PbHub Device
        i2c_device_config_t hub_cfg = {}; // Zero-initialize all fields first
        hub_cfg.dev_addr_length = I2C_ADDR_BIT_LEN_7;
        hub_cfg.device_address = i2c_addr_;
        hub_cfg.scl_speed_hz = 100000;
        
        if (i2c_master_bus_add_device(bus_handle, &hub_cfg, &dev_hub_handle_) != ESP_OK) {
            return false;
        }

        // 2. Configure and add Scale Device
        i2c_device_config_t scale_cfg = {}; // Zero-initialize all fields first
        scale_cfg.dev_addr_length = I2C_ADDR_BIT_LEN_7;
        scale_cfg.device_address = SCALE_I2C_ADDR;
        scale_cfg.scl_speed_hz = 100000;

        if (i2c_master_bus_add_device(bus_handle, &scale_cfg, &dev_scale_handle_) != ESP_OK) {
            return false;
        }

        return true;
    }

    /**
     * @brief Check if the device responds over I2C (replaces Wire.endTransmission logic)
     */
    bool check_status()
    {
        if (!bus_handle_) return false;
        // Correct signature: probe(bus_handle, 7bit_address, timeout_ms)
        return (i2c_master_probe(bus_handle_, i2c_addr_, I2C_TIMEOUT_MS) == ESP_OK);
    }

    // ── GPIO bolt sensors ─────────────────────────────────────────────────────
    bool is_bolt_at_start() const { return gpio_get_level(PIN_BOLT_START) == 0; }
    bool is_bolt_at_end()   const { return gpio_get_level(PIN_BOLT_END)   == 0; }

    // ── Scale ─────────────────────────────────────────────────────────────────
    float read_scale_weight_g()
    {
        if (!dev_scale_handle_) return -999.0f;

        uint8_t reg = 0x10;
        esp_err_t err = i2c_master_transmit(dev_scale_handle_, &reg, 1, I2C_TIMEOUT_MS);
        if (err != ESP_OK) return -999.0f;

        // delay(5) -> Convert to FreeRTOS ticks
        vTaskDelay(pdMS_TO_TICKS(5));

        uint8_t data[4] = {0};
        err = i2c_master_receive(dev_scale_handle_, data, 4, I2C_TIMEOUT_MS);
        if (err != ESP_OK) return -999.0f;

        float weight;
        std::memcpy(&weight, data, 4);
        return weight;
    }

    void tare_scale()
    {
        if (!dev_scale_handle_) return;
        uint8_t buf[2] = {0x50, 0x01};
        i2c_master_transmit(dev_scale_handle_, buf, sizeof(buf), I2C_TIMEOUT_MS);
    }

    void set_scale_led_color(uint32_t rgb_24bit)
    {
        if (!dev_scale_handle_) return;
        uint8_t buf[4] = {
            0x30,
            static_cast<uint8_t>((rgb_24bit >> 16) & 0xFF),
            static_cast<uint8_t>((rgb_24bit >> 8)  & 0xFF),
            static_cast<uint8_t>(rgb_24bit         & 0xFF)
        };
        i2c_master_transmit(dev_scale_handle_, buf, sizeof(buf), I2C_TIMEOUT_MS);
    }
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

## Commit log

2026-02-12 Initial CAD design
    [BoltTaskAssembly_v2.FCStd]
2026-02-12 Update sensoless design
    [BoltTaskAssembly_v2.FCStd]
2026-02-12 Refactor assembly types
    [BoltTaskAssembly_TypeA_V1.FCStd, BoltTaskAssembly_TypeB_V1.FCStd, BoltTaskAssembly_v1.FCStd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]
2026-02-12 Refactor for the two design types
    [BoltTaskAssembly_TypeA_V1-Base.stl, BoltTaskAssembly_TypeA_V1-BaseBracket.stl, BoltTaskAssembly_TypeA_V1-Main.stl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]
2026-02-13 Update Type B CAD design
    [BoltTaskAssembly_TypeB_V1.FCStd]
2026-02-13 Add Type B STLs
    [BoltTaskAssembly_TypeB_V1-Base.stl, BoltTaskAssembly_TypeB_V1-BaseBracket.stl, BoltTaskAssembly_TypeB_V1-Bottom.stl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]
2026-02-20 Add Type B V2
    [Base.stl, BaseMountBlockDIN.stl, BoltTaskAssembly_TypeB_V1-Base.stl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]
2026-02-25 Add V2 Main_25mm.stl
    [BoltTaskAssembly_TypeB_V2.FCStd, Main_25mm.stl]
2026-02-27 Add STEPs for Type B V2
    [BoltTaskAssembly_TypeB_V2-Assembly.step, BoltTaskAssembly_TypeB_V2-Base.step, BoltTaskAssembly_TypeB_V2-BaseMountBlockDIN.step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]
2026-05-30 Add the new Arduino firmware
2026-06-03 Update Bolt Addon Protocol
2026-07-23 Add modified forged base
    [Base_Forged.stl, BoltTaskAssembly_TypeB_V2.FCStd]
